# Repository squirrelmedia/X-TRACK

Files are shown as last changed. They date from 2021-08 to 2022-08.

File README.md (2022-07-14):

# X-TRACK
> 开源GPS自行车码表。
> 
> 拥有可显示实时位置的离线地图。
> 
> 支持记录和显示实时轨迹以及导出标准GPX格式的轨迹文件。
> 
> 全新设计的["页面生命周期管理"](https://github.com/FASTSHIFT/X-TRACK/tree/main/Software/X-Track/USER/App/Utils/PageManager)和["消息订阅发布框架"](https://github.com/FASTSHIFT/X-TRACK/tree/main/Software/X-Track/USER/App/Utils/DataCenter)。
>
> 演示视频：https://www.bilibili.com/video/BV1GB4y1K7VV



## GUI
> [LVGL V8](https://github.com/lvgl/lvgl)

## 硬件配置
* 1.主控: AT32F435CGU7 (主频:288MHz RAM:512KB ROM:1MB)
* 2.屏幕: ST7789 IPS 1.54inch SPI接口 240x240分辨率 60Hz刷新率
* 3.储存器: Micro SD CARD 32GB 
* 4.输入设备: 旋转编码器
* 5.RTC: MCU内置RTC时钟
* 6.加速度计: LSM6DSM (支持硬件计步输出)
* 7.地磁计: LIS3MDL
* 8.GPS: ATGM336H (BDS + GPS + GLONASS + GALILEO + QZSS + SBAS)
* 9.电池: Li-ion 3.7V 683030 700mAh
* 10.电源管理: LP5907-3.3 + MCP73831
* 11.外壳: 3D打印 光固化

## 功能
* 1.支持速度、距离、时间、卡路里、航向显示
* 2.拥有**离线地图**，支持显示实时位置，支持缩放
* 3.支持计步
* 4.支持经纬度、海拔显示
* 5.支持RTC自动根据GPS校准
* 6.支持记录轨迹，可导出[GPX格式](https://zh.wikipedia.org/wiki/GPX)的文件
* 7.支持掉电自动保存数据(JSON格式文件)
* 8.四小时续航 (持续工作，始终亮屏)
* 9.支持在[PC模拟器](https://github.com/FASTSHIFT/X-TRACK/tree/main/Software/X-Track/Simulator)模拟，脱离硬件调试(配置为**Release x86**)
* 10.支持显示实时轨迹
* 11.待续...

## 实物演示
### 测速
https://user-images.githubusercontent.com/26767803/120889722-1f8d8e80-c631-11eb-8294-df79f151dedb.mp4

### 历史轨迹显示([GPXSee](https://github.com/tumic0/GPXSee))


## 致谢
> 感谢[@davidce](https://www.geek-workshop.com/home.php?mod=space&uid=204)贡献的参考设计“[自制基于arduino的GPS地图导航系统3.0](https://www.geek-workshop.com/thread-8835-1-1.html)”。

> 感谢[@W-Mai](https://github.com/W-Mai)改进的[地图下载链接生成工具](https://github.com/W-Mai/XLocateDownloader/releases/download/1.0.0/MapDownloader.zip)、[地图下载器](https://github.com/W-Mai/XLocateDownloader)、[LVGL图片转换器(Python版)](https://github.com/W-Mai/lvgl_image_converter)、[批量文件重命名工具](https://github.com/W-Mai/filename_renamer)。

> 感谢[@Trigger-CN](https://github.com/Trigger-CN)的[UI设计](https://github.com/FASTSHIFT/X-TRACK/tree/main/ArtDesign)。

> 感谢[@MouriNaruto](https://github.com/MouriNaruto)的LVGL Visual Studio模拟器[lv_sim_visual_studio](https://github.com/lvgl/lv_sim_visual_studio)。

> 感谢[@dj140](https://github.com/dj140)编写[地图下载教程](https://github.com/FASTSHIFT/X-TRACK/blob/main/Tools/README.md)。

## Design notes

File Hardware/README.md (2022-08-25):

## 编译
* 参见: [编译说明](https://github.com/FASTSHIFT/X-TRACK/blob/main/Software/README.md)

## 硬件修改
* PCB打样的厚度选择**0.8mm**或**1mm**。
* 去除**D4**二极管，防止充电时自动开机，导致充电变慢和发热。
* 注意**D2**二极管方向，方向是和其他二极管相反的。否则会发生开机一段时间自动关机的情况。
* GPS模块需要由**HT1818Z3G5L**更换为**ATGM336H**(购买链接在下方)，否则外壳放不下。关于接线，GPS模块的**TX**脚接板子的**T焊盘**,**RX**脚接板子的**R焊盘**。注意GPS的天线**不要**碰到旁边的法拉电容，否则导致模块发热且收不到信号。
* 地磁计**LIS3MDL**和加速度计**LSM6DSM**在该系统中作用不大，又由于芯片涨价导致整机成本过高，可以不安装。
* MCU:**AT32F435CGU7**或**AT32F403ACGU7**
如果定不到货，可以尝试[@johnsbark](https://github.com/johnsbark)设计的[改进版硬件](https://github.com/FASTSHIFT/X-TRACK/tree/main/Hardware/X-TRACK%20%E6%94%B9%E8%BF%9B%E7%89%88)方案（红框内的MCU都可以进行尝试）。

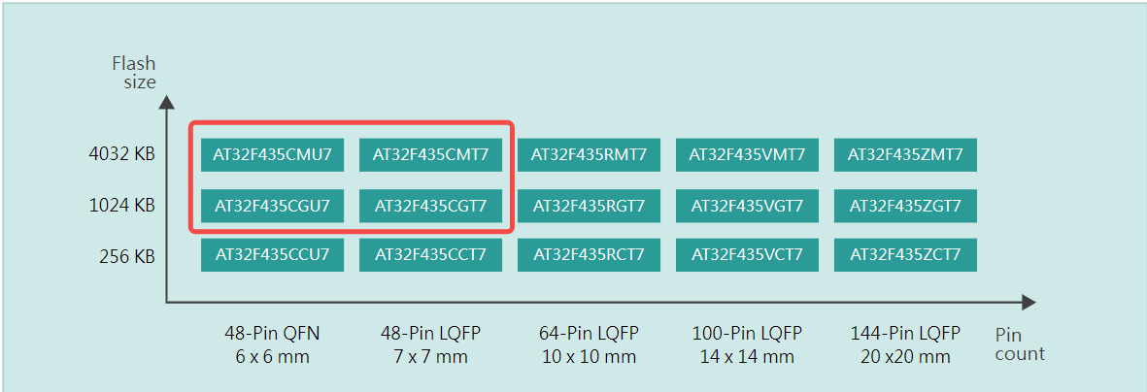
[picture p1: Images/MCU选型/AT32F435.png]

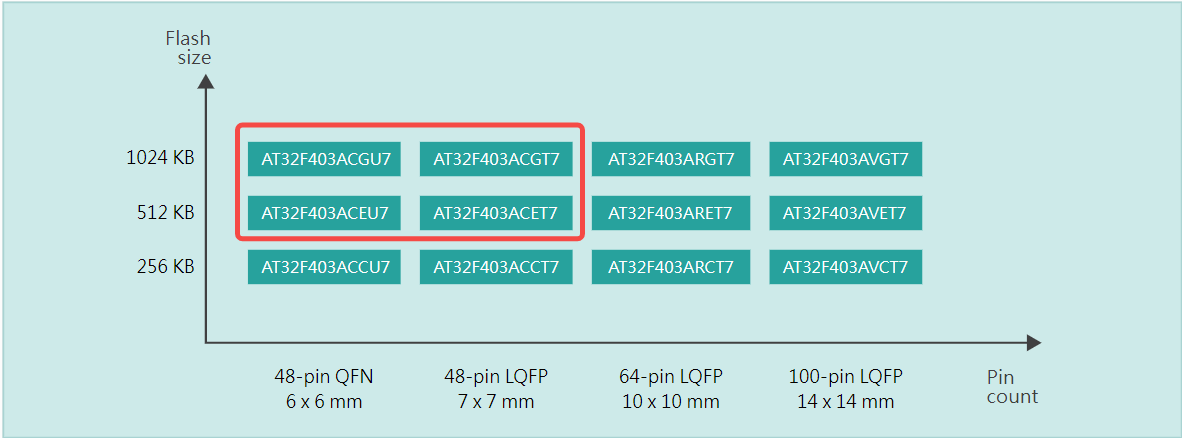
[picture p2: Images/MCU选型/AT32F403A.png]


* 关于其他品牌MCU替换的性能需求: 主频 >150M，RAM >=200K，FLASH >=512K，SPI速度 >=50Mbps。 

## 特殊器件购买链接
* 电池 (选择 683030) https://detail.tmall.com/item.htm?id=634173891714
* 旋转编码器 https://item.taobao.com/item.htm?id=598028191617
* 屏幕 (选择 裸屏) https://item.taobao.com/item.htm?id=600653923469
* 调试口 (选择 4P弯针) https://item.taobao.com/item.htm?id=522574977704
* 码表底座 (选择 竖向按装拓展片孔距M3*20~21mm[塑胶材料 3g]) https://item.taobao.com/item.htm?id=599529362799
* GPS模块 (ATGM336H) https://item.taobao.com/item.htm?id=603186739934
* AON3400 (AO3400 N沟道MOS管) https://item.taobao.com/item.htm?id=522574089119
* 侧盖螺丝 https://item.taobao.com/item.htm?id=522574685586
* Pad (焊接电池线的焊盘，非实体元件)

## 焊接
* [焊接教程](https://github.com/FASTSHIFT/X-TRACK/blob/main/Hardware/%E7%84%8A%E6%8E%A5%E8%B0%83%E8%AF%95%E6%8C%87%E5%8C%97.md)

## 常见故障排查
> GPS连不上
* 到开阔地带进行定位
* 进入系统信息页面查看GPS栏是否能获取到UTC时间
* 如果一直无法获取UTC时间，则检查GPS模块和MCU的硬件连接，确保通信波特率为9600
* 检查GPS天线朝向，参考下图

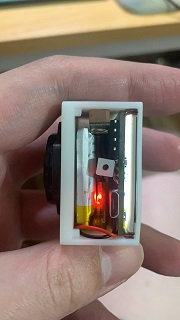
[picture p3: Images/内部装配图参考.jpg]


> 地图不显示
* 在首次定位成功前，默认加载的地图区域是北京，等待定位成功或者修改**SystemSave.json**里的经纬度配置
* 检查状态栏是否有SD卡图标
* 检查地图文件路径是否为`/MAP/z/x/y.bin`
* **不要使用旧版地图工具**

> 不开机 & 关不了机
* 长按编码器开关机
* 检查供电是否正常，MCU和其他器件上的电压是否是3.3V

> 开机了但黑屏
* 检查屏幕排线和MCU间是否短路或虚焊
* 检查背光是否有电压

> SD卡无法读取
* 在系统信息页面查看"Storage"项，是否能正常读取到SD卡容量和类型
* 检查SD卡座和MCU间是否有短路或虚焊
* 检查SD卡格式是否为FAT32

> SD卡内没有生成**SystemSave.json**配置文件
* **SystemSave.json**在第一次关机后自动生成

> 地图坐标有恒定偏移
* 尝试修改SD卡根目录下的**SystemSave.json**里的**useWGS84**选项[配置地图坐标系统](https://github.com/FASTSHIFT/X-TRACK/tree/main/Software#%E7%B3%BB%E7%BB%9F%E9%85%8D%E7%BD%AE%E6%96%87%E4%BB%B6)

> 速度不准
* 不同厂家的GPS模块性能不一，测得的速度可能会有小幅度跳动(<±2KM/h)
* 检查GPS天线朝向，参考第一点
* 更换GPS模块

> PC模拟器上无法显示地图/显示颜色异常
* MAP地图文件夹放在X-TRACK工程的根目录`~/X-TRACK/MAP/`
* 修改**SystemSave.json**里的经纬度配置到希望显示地图的地方
* 确认生成的地图文件命名格式为`/z/x/y.png`
* 修改**SystemSave.json**的`"sysConfig.mapExtName"`项目，将`"bin"`改为`"png"`

## 2.0寸屏版本
https://github.com/FASTSHIFT/X-TRACK/tree/2.0-inch by[@HanfG](https://github.com/HanfG)

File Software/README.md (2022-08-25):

## 编译说明
* MCU固件: 务必使用**Keil v5.25**或以上的版本进行编译（旧版本编译器不能完全支持**C++ 11**的语法），在Keil中编译器版本设置为ARM Compiler 5。
* 编译前需要安装[Artery](https://www.arterytek.com/cn/index.jsp)官方Pack，**为了确保顺利编译请安装[Software/Pack](https://github.com/FASTSHIFT/X-TRACK/tree/main/Software/Pack)目录下的指定版本**。

* 如果安装Pack后，Keil依然报以下这类错误，可能是之前安装了 Keil v4 兼容包 (MDK v4 Legacy Support) 导致的，请尝试**卸载此包或重新安装 Keil v5**。

`Error #540: 'Keil::Device:StdPeriph Drivers:ADC:1.0.1' component is not available for target 'X-Track'`
 
  ### 注意
  **不要修改芯片选型**，因为修改芯片选型后启动文件会重新生成，堆栈大小会恢复默认值，而使用默认的栈大小会导致**栈溢出**。现象是启动后立即蓝屏，提示发生**HardFault**(如下图所示)，串口会输出详细的错误信息。如果确实需要修改芯片选型，请参考工程原始的启动文件进行修改。



## VS模拟器配置
* 编译：使用`Visual Studio 2019`编译，配置为`Release` `x86`模式，`Debug`模式需要额外安装[ASAN](https://docs.microsoft.com/en-us/cpp/sanitizers/asan?view=msvc-170)插件。
* 文件配置：

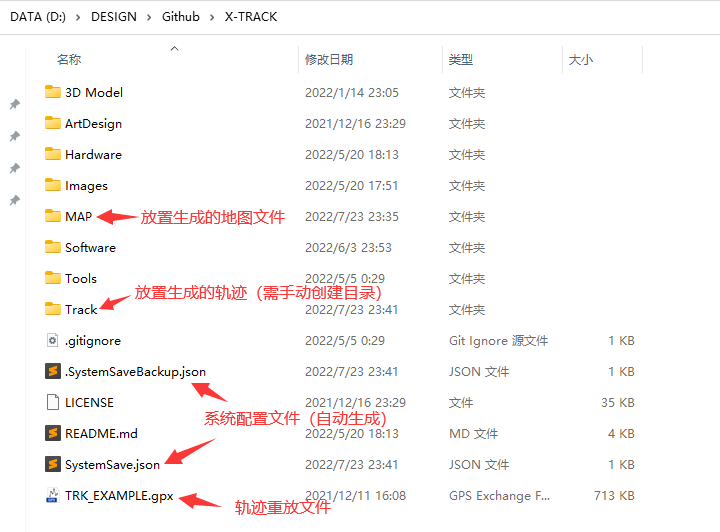
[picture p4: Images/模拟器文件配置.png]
images


## 系统配置文件
系统会在根目录下自动生成`SystemSave.json`的文件，用于储存和配置系统参数:
```javascript
{
  "sportStatus.totalDistance": 0,              // 总里程(m)
  "sportStatus.totalTimeUINT32[0]": 0,         // 总行驶时间(ms)，低32位
  "sportStatus.totalTimeUINT32[1]": 0,         // 总行驶时间(ms)，高32位
  "sportStatus.speedMaxKph": 0,                // 最高时速(km/h)
  "sportStatus.weight": 65,                    // 体重(kg)
  "sysConfig.longitude": 116.3913345,          // 上次开机记录的位置(经度)
  "sysConfig.latitude": 39.90741348,           // 上次开机记录的位置(纬度)
  "sysConfig.soundEnable": 1,                  // 系统提示音使能(1:开启，0:关闭)
  "sysConfig.timeZone": 8,                     // 时区(GMT+)
  "sysConfig.language": "en-GB",               // 语言(尚不支持多语言切换)
  "sysConfig.arrowTheme": "default",           // 导航箭头主题(default:全黑，dark:橙底黑边，light:橙底白边)
  "sysConfig.mapDirPath": "/MAP",              // 存放地图的文件夹路径
  "sysConfig.mapExtName": "bin",               // 地图文件扩展名
  "sysConfig.mapWGS84": 0                      // 坐标系统配置(0:GCJ02, 1:WGS84)
}
```

## 目录结构
```
 X-Track
    ├─ArduinoAPI                -- 通用 Arduino API 抽象层
    ├─Doc                       -- 芯片相关文档
    ├─Libraries                 -- 硬件驱动程序
    │  ├─Adafruit_GFX_Library   -- Adafruit_GFX轻量级图形库
    │  ├─Adafruit_ST7789        -- ST7789屏幕驱动
    │  ├─ButtonEvent            -- 按键事件库
    │  ├─cm_backtrace           -- ARM Cortex-M 系列 MCU 错误追踪库
    │  ├─LIS3MDL                -- LIS3MDL地磁计驱动
    │  ├─LSM6DSM                -- LSM6DSM陀螺仪加速度计驱动
    │  ├─MillisTaskManager      -- 合作式任务调度器
    │  ├─SdFat                  -- 文件系统
    │  ├─StackInfo              -- 栈空间使用统计库
    │  └─TinyGPSPlus            -- NMEA协议解析器
    ├─MDK-ARM_F403A             -- AT32F403A Keil工程
    ├─MDK-ARM_F435              -- AT32F435  Keil工程
    ├─Simulator                 -- Visual Studio LVGL PC模拟器
    ├─Tools                     -- 实用工具
    └─USER                      -- 用户程序
        ├─App                   -- 应用层
        │  ├─Common             -- 通用程序
        │  │  ├─DataProc        -- 应用后台数据处理
        │  │  ├─HAL             -- 硬件抽象层定义/Mock实现
        │  │  └─Music           -- 操作音管理
        │  ├─Config             -- 应用配置文件
        │  ├─Pages              -- 页面
        │  │  ├─Dialplate       -- 表盘页面
        │  │  ├─LiveMap         -- 地图页面
        │  │  ├─Startup         -- 开机页面
        │  │  ├─StatusBar       -- 状态栏
        │  │  ├─SystemInfos     -- 系统信息页面
        │  │  └─_Template       -- 页面模板
        │  ├─Resource           -- 资源池
        │  │  ├─Font            -- 字体
        │  │  └─Image           -- 图片
        │  └─Utils              -- 通用应用层组件
        │      ├─ArduinoJson    -- JSON库
        │      ├─DataCenter     -- 消息发布订阅框架
        │      ├─Filters        -- 常用滤波算法库
        │      ├─GPX            -- GPX生成器
        │      ├─GPX_Parser     -- GPX解析器
        │      ├─lv_allocator   -- 自定义allocator
        │      ├─lv_anim_label  -- 文本动画组件
        │      ├─lv_ext         -- lvgl功能扩展
        │      ├─lv_img_png     -- PNG显示组件
        │      ├─lv_poly_line   -- 多段线控件
        │      ├─MapConv        -- WGS84/GCJ02 地图坐标转换器
        │      ├─new            -- new/delete 重载
        │      ├─PageManager    -- 页面调度器
        │      ├─PointContainer -- 坐标压缩容器
        │      ├─ResourceManager-- 资源管理器
        │      ├─StorageService -- KV储存服务
        │      ├─Stream         -- Arduino Stream 流式库
        │      ├─TileConv       -- 瓦片坐标转换器
        │      ├─Time           -- 时间转换算法库
        │      ├─TonePlayer     -- 异步方波音乐播放器
        │      ├─TrackFilter    -- 流式轨迹坐标拐点/线段提取器
        │      └─WString        -- Arduino WString 字符串库
        ├─HAL                   -- 硬件抽象层
        └─lv_port               -- lvgl与硬件的接口
```

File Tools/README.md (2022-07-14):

# 地图下载说明

## 1.下载安装[Crimson/地图下载器](https://gitee.com/CrimsonHu/java_map_download/)

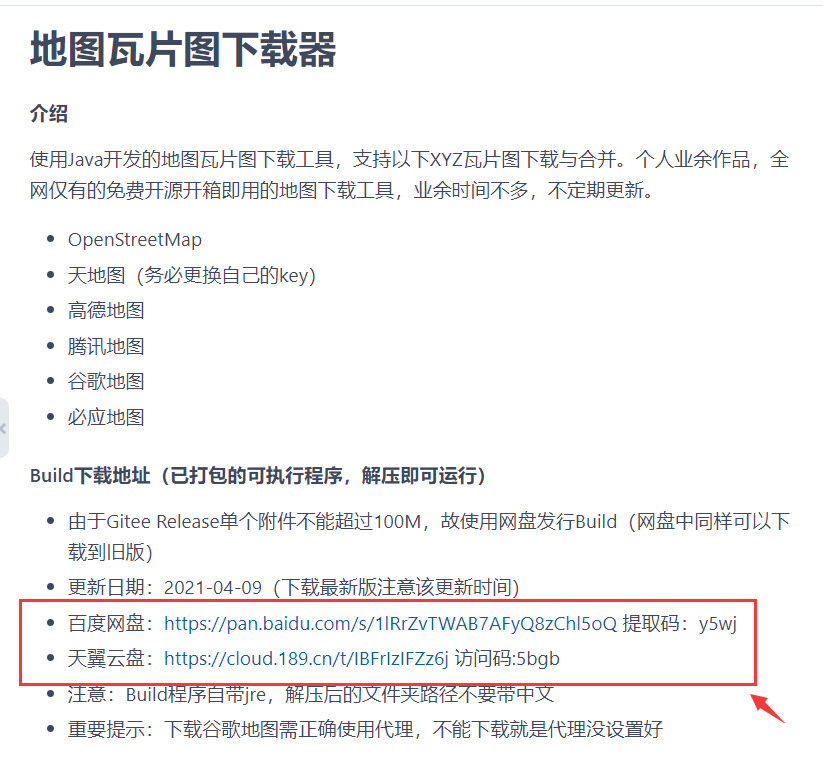
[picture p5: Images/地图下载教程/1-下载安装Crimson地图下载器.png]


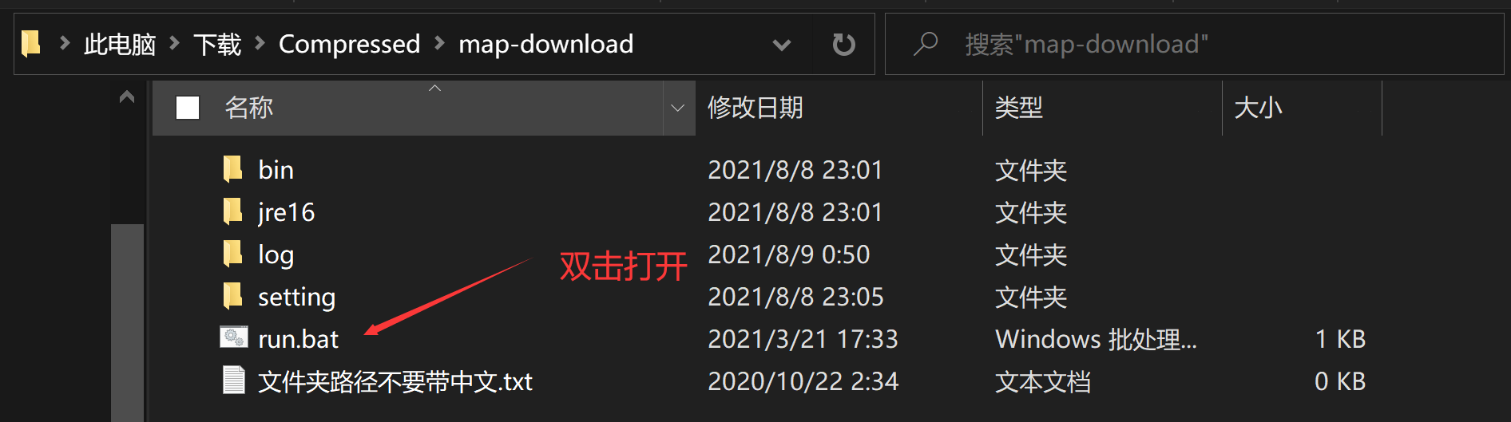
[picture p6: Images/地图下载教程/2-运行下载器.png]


## 2.选择要下载的地图区域
 * 选择自己所在区域下载即可，**切勿选择过大范围**，下载区域设置小一些后续下载会快很多。
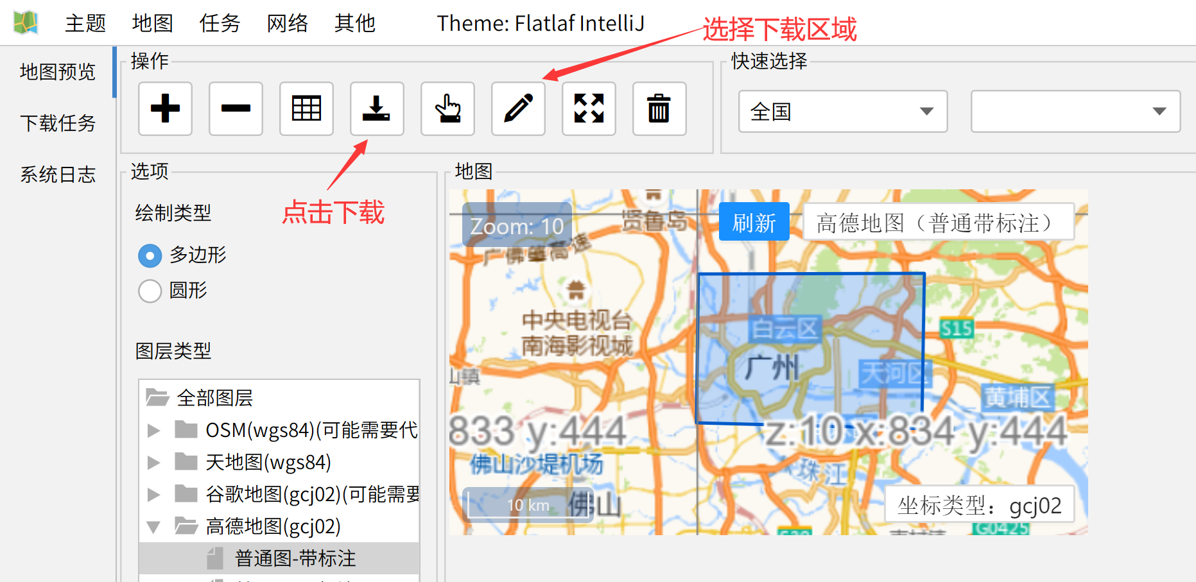
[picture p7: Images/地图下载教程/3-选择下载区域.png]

## 3.下载地图
 * 下载地图等级根据自己喜好选择，等级越高地图越详细，但是文件也越大（建议只勾选**0~16级**，如果出现0~2级下载失败的情况，可以不勾选）。命名格式为`/z/x/y.png`格式，保存路径新建一个`MAP`文件夹
 
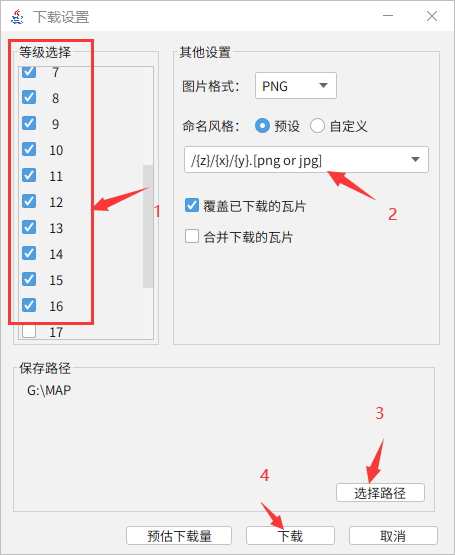
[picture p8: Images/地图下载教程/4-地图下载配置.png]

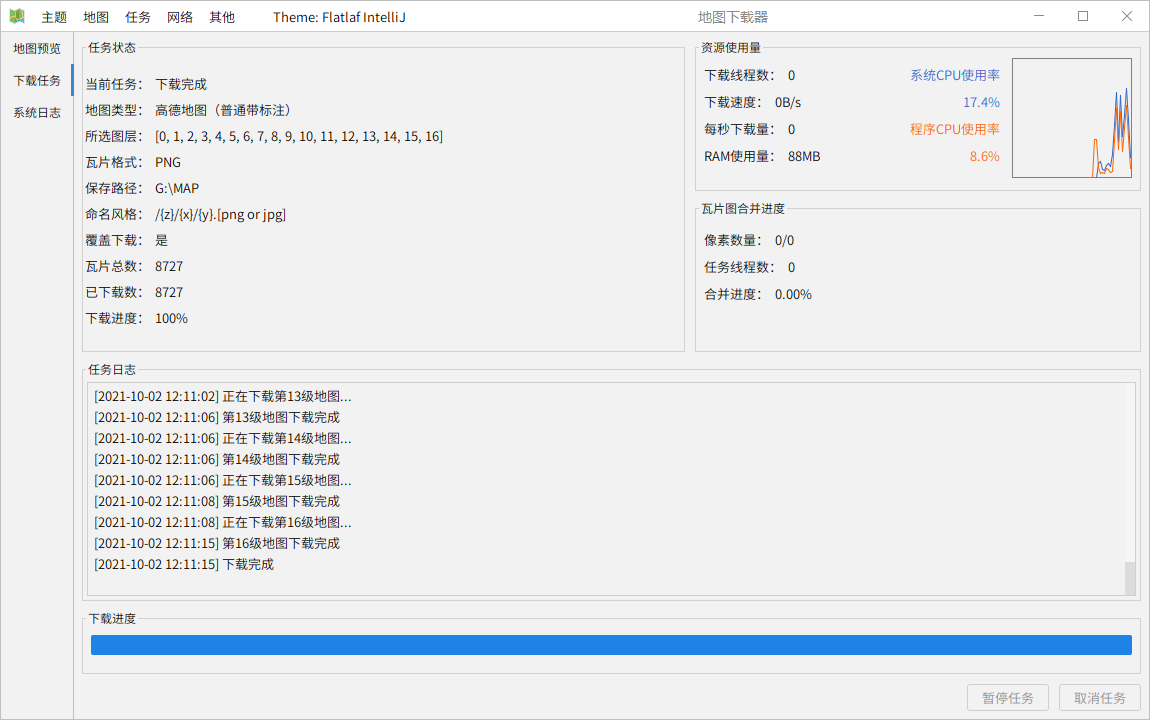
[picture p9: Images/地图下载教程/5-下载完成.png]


## 4.转换地图文件
* 下载完成后，使用`Tools`文件夹下的`TilesConverterForLVGL.exe`进行转换（[使用教程](https://github.com/FASTSHIFT/X-TRACK/tree/main/Images/MapConverter%E4%BD%BF%E7%94%A8%E6%95%99%E7%A8%8B)）




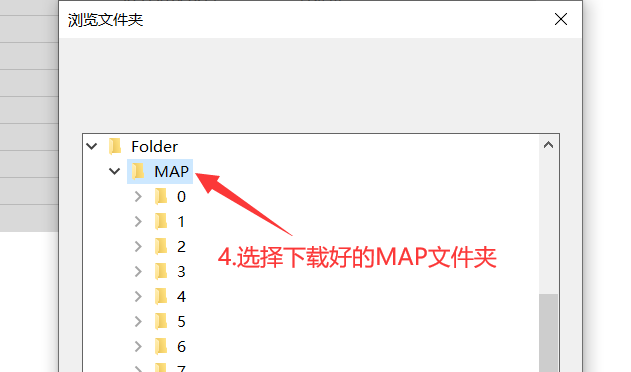
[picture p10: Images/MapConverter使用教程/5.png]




## 5.拷贝"MAP"文件夹至SD卡根目录
### 注意：
 * SD卡需要格式化为**FAT32格式**。
 * SD卡插入开机以后，会在第一次关机时自动创建`SystemSave.json`文件，其中：
 > 通过`"mapDirPath"`设置地图源文件夹，默认路径为`"/MAP"`（SD卡可以储存多个地图源，通过此选项切换）
 > 
 > 通过`"mapWGS84"`设置坐标系统，如果发现地图偏移请尝试修改。
 * `SystemSave.json`文件详细说明见[编译说明](https://github.com/FASTSHIFT/X-TRACK/blob/main/Software/README.md)。

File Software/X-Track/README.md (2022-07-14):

# X-TRACK 更新日志
> https://github.com/FASTSHIFT/X-TRACK

## [v0.1] - 2021-3-21
* 1.框架搭建完成，全新MVP(Model-View-Presenter)架构
* 2.更新3D Model，门板完美安装
* 3.修复串口缓冲队列过载导致GPS解析连续失败的BUG
* 4.添加长按开机功能
* 5.添加计步显示
* 6.速度显示使用kph为单位
* 7.添加新的ButtonEvent库
* 8.添加Filters数字滤波器库 
* 9.添加新的TonePlayer库
* 10.格式化LIS3DMDL库的代码
* 11.格式化LISM6DSM库的代码
* 12.添加新的简易表盘页面
* 13.为LiveMap页面添加group，优化Encoder交互
* 14.LiveMap已可以正常显示航向，使用GPS的航向信息
* 15.重新校准MapConv地图坐标
* 16.添加HAL_AHRS姿态解算
* 17.添加HAL_Encoder接口
* 18.添加HAL_GPS串口透传，可使用上位机对GPS模块进行配置
* 19.添加GNSSToolKit_Lite配置工程
* 20.添加lv_get_indev()
* 21.添加__wfi()，可能省点电

## [v0.2] - 2021-4-19
* 1.添加ArtDesign工程，使用Adobe Illustrator
* 2.添加异步无锁Buffer库：PingPongBuffer
* 3.删除离线图片和字体转换工具
* 4.修改页面ID格式：DialplatePage->Pages/Dialplate
* 5.添加消息发布订阅框架：DataCenter
* 6.将HAL.h转移至应用层
* 7.HAL: Clock_GetValue->Clock_GetInfo
* 8.在PC模拟器上使用PC的电量显示
* 9.更新PageManager
* 10.降低SD热插拔监控扫描速度
* 11.删除Music_Astronomia
* 12.在编码器按下时忽略滚动，减少误触
* 13.更新Dialplate页面
* 14.更新LiveMap页面

## [v0.3] - 2021-5-12
* 1.lvgl迁移至v8.0.0
* 2.PingPongBuffer转移至App/Utils/DataCenter，以提供无锁的线程安全的数据块访问，添加volatile关键字
* 3.VS工程在Debug下启用AddressSanitizer，捕获异常的内存操作
* 4.Heap和Stack调整
* 5.更新ButtonEvent库
* 6.更换新的文件系统接口lv_fs_if
* 7.系统配置文件SysConfig.h -> Config.h
* 8.Utils添加WString for PC
* 9.ResourceManager更新，使用std::vector作为资源池
* 10.PageManager更新，lvgl-v8适配，简化子模块命名，使用std::vector作为页面池，使用std::stack作为页面栈
* 11.地图坐标转换器MapConv更新，但未找到更精确的地图坐标换算算法
* 12.去除lv_theme_custom
* 13.添加GPX库，将来用于生成GPX格式的标准轨迹记录文件
* 14.使用C++ template重写Filters滤波器合集库
* 15.数据发布订阅处理中心DataCenter更新，添加错误码、通知、数据提交等功能
* 16.StatusBar更新，添加背景色柔和渐变、电池充电等特效
* 17.LiveMap页面更新，新的滚动条和info按钮
* 18.Dialplate页面更新，操作按钮已可以使用
* 19.数据处理节点DP_SportStatus更新，更新卡路里换算算法、距离、速度滤波等处理方法
* 20.添加新的数据处理节点DP_Recorder，用于记录轨迹于SD卡中
* 21.电池AD采样使用中断模式，而不使用DMA
* 22.文件系统SD对象不再全局共享
* 23.屏蔽开机启动时Encoder按键事件

## [v0.4] - 2021-5-16
* 1.lvgl更新
* 2.支持导出GPX格式的轨迹记录文件，推荐使用[GPXSee](https://github.com/tumic0/GPXSee)查看轨迹
* 3.Clock_info_t结构体成员单词全拼
* 4.LiveMap页面更新，改进的操作方式与显示特效
* 5.去除MAP数据映射宏，使用lv_map替代
* 6.SD支持时间戳记录，支持自动检测和创建缺失的文件夹

## [v0.5] - 2021-5-23
* 1.添加SystemInfos页面
* 2.添加IMU和地磁MAG数据处理节点
* 3.修改轨迹记录默认文件名
* 4.规范lv_event成员参数获取方式
* 5.修复DataCenter缓冲区读取释放BUG
* 6.添加Version.h存放版本信息
* 7.HAL::GPS_Info_t添加hour_utc成员

## [v0.6] - 2021-5-31
* 1.更新lvgl
* 2.添加App_Uninit()，绑定关机事件
* 3.添加DP_LIST.inc，更优雅的数据处理节点注册方式
* 4.添加IMU/MAG_Commit，向数据中心提交数据
* 5.添加StorageService数据储存服务，使用JSON格式储存数据
* 6.添加ArduinoJson解析库
* 7.运动数据处理节点 sportStatusInfo -> sportStatus，添加储存绑定
* 8.去除HAL::AHRS
* 9.GPS在未定位成功时，经纬度海拔统一置零
* 10.HAL::Power添加关机事件回调
* 11.CONTROLLER -> PRESENTER
* 12.添加Startup页面，展示开机动画
* 13.LiveMap地图页面，在未定位成功时的默认位置为天安门
* 14.StatusBar状态栏，函数AppearAnimStart -> Appear 
* 15.解决SystemInfos页面在自动管理Cache时退出页面造成的Crash
* 16.修复MAG数据显示的bug
* 17.DataCenter添加主账户AccountMain，自动订阅所有的子节点，用于发送通知
* 18.PageManager在删除root时需要使用异步删除lv_obj_del_async()，在root动画生命周期结束后删除
* 19.降低GPS和Sensor的数据更新频率，分别为5Hz和1Hz

## [v0.7] - 2021-6-5
* 1.更新拆分STL模型文件
* 2.TonePlayer转移至App/Utils
* 3.在关机时自动保存正在记录的轨迹文件
* 4.优化轨迹记录操作体验
* 5.DataCenter合并定时器回调到AccountEvent
* 6.AccountEvent添加Account* 参数
* 7.添加DATA_PROC_INIT_DEF节点定义
* 8.添加StatusBar状态栏、MusicPlayer播放器、TzConv时区转换器数据节点
* 9.优化电池电量滤波算法 Hysteresis + MedianQueue
* 10.转移STORAGE_VALUE_REG宏定义至DataProc_Def.h
* 11.在SD插入时自动加载JSON系统配置文件
* 12.添加Common/Music
* 13.优化DataCenter和PageManager日志输出等级
* 14.优化GPX库
* 15.优化PAGE_STASH_POP
* 16.去除PageManager::Pop函数的stash参数
* 17.添加Arduino Time时间转换库
* 18.去除GPS_Info_t的hour_utc成员，使用TzConv进行时区转换

## [v0.8] - 2021-6-15
* 1.格式化所有代码
* 2.APP_Init添加ACCOUNT_SEND_CMD，简化Account通知调用
* 3.dataCenter("Bilibili") -> dataCenter("CENTER")
* 4.添加SysConfig节点，用于保存系统设置
* 5.Power节点使用Account通知方式调用MusicPlayer，而不使用HAL::Audio_PlayMusic
* 6.去除HAL::Backlight_UpdateBKP()和Backlight_GetBKP()
* 7.DialplateModel添加节点名称验证
* 8.LiveMapModel添加节点名称验证
* 9.DataCenter添加Account双buffer动态内存申请检查
* 10.Account::GetPublisherLen() -> GetPublisherSize(), GetSubscribeLen() -> GetSubscribeSize()
* 11.更新lv_anim_timeline，支持设置progress，已提交至lvgl主线
* 12.去除lv_obj_ext_func不常用的函数
* 13.StorageService扩大JSON_BUFFER_SIZE 256 -> 512, 添加字符串类型参数读取返回值检查
* 14.添加硬件定时器配置到Config.h
* 15.修改版权声明遗留拼写错误

## [v0.9] - 2021-6-24
* 1.更新ButtonEvent，支持EVENT_LONG_PRESSED_RELEASED
* 2.调整lvgl内存池，32KB -> 64KB
* 3.HAL_GPS支持读取csv格式的文件，在PC上模拟位置变化
* 4.更新LiveMap页面，支持实时绘制运动轨迹，支持自适应分辨率动态加载地图
* 5.更新Startup页面，移除默认样式，并在开机动画过程中屏蔽Encoder事件
* 6.修复SystemInfos页面因为忘记释放style.focus导致的内存泄漏
* 7.优化DataCenter的Account的cache申请失败判断逻辑
* 8.添加lv_allocator，使用lvgl接管std::vector内存管理实现
* 9.更新MapConv，MapKeyRootName -> MapFilePath，ConvertMapTile() -> ConvertPosToTile()
* 10.添加TileConv，通用的瓦片动态加载算法实现
* 11.添加TrackFilter轨迹过滤器，包含TrackPointFilter曲线关键点提取算法和TrackLineFilter曲线区域裁剪算法
* 12.HAL::Encoder添加Encoder_SetEnable()方法

## [v1.0] - 2021-7-1
* 1.更新lvgl v8.1.0 dev
* 2.添加TrackFilter数据处理节点，储存过滤后的拐点坐标
* 3.优化DP_Clock RTC自动校准
* 4.优化DP_GPS提示音播放，添加cache，使用Publish向订阅者推送数据，减少定时轮询拉取
* 5.添加GPX_Parser，支持直接解析GPX数据还原轨迹
* 6.Config.h转移到App
* 7.页面添加namespace Page命名空间
* 8.优化LiveMap轨迹显示，在轨迹记录时显示轨迹，使用lambda表达式替换部分回调函数
* 9.优化StatusBar充电动画
* 10.DataCenter添加注释
* 11.PageManager添加注释
* 12.lv_allocater添加遗漏的运算符重载
* 13.添加Utils/Stream，来自Arduino
* 14.转移CommmonMacro.h到HAL，去除Basic文件夹

## [v1.1] - 2021-7-7
* 1.支持在GPX中记录海拔和时间，可在GPXSee查看爬升和速度统计
* 2.更新Startup页面，使用匿名函数回调
* 3.更新SystemInfos页面，添加Author署名和Build时间，电池状态 State -> Status
* 4.更新lvgl
* 5.更新GPX生成库，添加遗漏的time_成员
* 6.尝试将lvgl部分函数放在RAM中执行，但是执行速度提升不明显

## [v1.2] - 2021-7-11
* 1.添加StackInfo库，支持在裸机环境下测量栈使用情况
* 2.Stack_Size 0x2500 -> 0x1000
* 3.更新DP_Storage数据储存节点，支持拉取储存器使用情况
* 4.更新Config.h，添加显示器分辨率和缓冲区配置
* 5.添加触控逻辑
* 6.修复StatusBar充电动画闪烁的BUG，添加SD卡图标
* 7.SystemInfos页面添加SD卡状态监测显示

## [v1.3] - 2021-7-18
* 1.Config.h添加传感器使能配置选项
* 2.DataCenter添加cache自动初始化置0
* 3.添加Microsoft官方TileSystem解析库，供mapConv调用

## [v1.4] - 2021-7-24
* 1.更新lvgl
* 2.更新MapConv，统一使用GPS_Transform校准坐标
* 3.更新HAL::GPS模拟，支持航向和速度模拟
* 4.修改HAL::GPS_Info_t的 compass -> course
* 5.使用合入lvgl主线的lv_anim_timeline，使用lv_anim_timeline_wrapper封装动画组
* 6.更新Startup页面，新的开机动画
* 7.LV_IMG_CACHE_DEF_SIZE设置为0

## [v1.5] - 2021-8-1
* 1.lvgl更新
* 2.调整Stack size: 0x1500 -> 0x2000，处理更大的JSON文件
* 3.更新Storage节点，支持获取SD卡容量，支持自动获取地图缩放等级(OSM)
* 4.优化GPS节点，减少在GPS信号不稳定时频繁的提示音
* 5.优化SportStatus节点，支持在JSON文件中配置体重
* 6.优化SysConfig节点，支持在JSON配置默认经纬度，地图源(Bing/OSM)，soundDisable -> soundEnable
* 7.重构MapConv地图坐标转换器，支持动态配置地图源，地图坐标数据类型uint32_t -> int32_t，合并TileSystem和GPS_Transform
* 8.HAL添加SD_GetCardSizeMB()
* 9.更新Config.h，转移部分配置选项到JSON
* 10.更新Dialplate页面，卡路里单位cal -> k，优化编码器交互wrap = false
* 11.更新LiveMap页面，优化level自适应显示，使用SysConfig配置的默认位置
* 12.更新SystemInfos页面，支持显示SD卡容量
* 13.修复lv_fs_sdfat错误的指针类型转换，优化目录读取接口
* 14.lvgl内存池 64K -> 72K
* 15.WString使用lvgl的内存池
* 16.修复GPX轨迹文件<\ele>丢失问题(可能是内存碎片和heap过小导致WString realloc失败)

## [v1.6] - 2021-8-7
* 1.更新ArtDesign，新的导航箭头设计
* 2.更新lv_drivers，去除坐标超界警告
* 3.去除lv_examples，减少工程体积
* 4.调整模拟器的LV_FS_PC_PATH定义，指定到Software所在目录，方便读取地图
* 5.开机页面重命名: StartUp -> Startup
* 6.更新DP_SysConfig，mapSource -> mapDirPath指定地图目录，添加 WGS84/GCJ02 坐标系统切换，添加arrowTheme导航箭头主题切换
* 7.更新DP_Storage，适配新的MapConv，支持所有地图源缩放level范围自适应
* 8.更新DP_TrackFilter，适配新的MapConv
* 9.HAL添加Backlight_ForceLit()，支持强制点亮屏幕背光
* 10.更新模拟器的HAL_GPS，支持获取GPX点之间的时间差
* 11.更新Config.h，去除旧的Bing地图配置
* 12.更新LiveMap页面，支持修改导航箭头主题
* 13.更新GPX_Parser，添加海拔和时间解析
* 14.重构MapConv，废弃旧的Bing地图存放格式和地图下载器。使用[Crimson/地图下载器](https://gitee.com/CrimsonHu/java_map_download/)下载地图，文件存放格式为`/z/x/y.bin`
* 15.更新DisplayFault，在进入HardFault状态时强制点亮背光
* 16.更新HAL_Power，优化电压显示

## [v1.7] - 2021-9-3
* 1.调整Heap_Size 0x00002000 -> 0x00000200
* 2.调整lvgl内存池大小，LV_MEM_SIZE 72K -> 80K
* 3.更新lv_drivers
* 4.更新lvgl
* 5.DataCenter使用lvgl内存池
* 6.使用std::abs()替代宏实现的ABS()
* 7.更新DP_Storage
* 8.更新DP_SysConfig，调整结构体成员，添加timeZone和mapExtName，在关机时保存位置
* 9.更新DP_TrackFilter，使用地图上的Point格式替代旧的经纬度
* 10.更新DP_TzConv，GMT_OffsetHours -> sysCfg.timeZone
* 11.更新HAL.h，添加Memory_DumpInfo()堆栈使用统计
* 12.更新HAL_GPS模拟，修复diffTime = 0导致的gpsInfo.speed = inf
* 13.更新Config.h，添加LiveMap的Debug模式配置，PNG解码库使能配置等。转移Hardware Configuration至HAL_Config.h
* 14.更新Dialplate页面，使用lv_group_get_default()获取统一的group
* 15.重构LiveMap页面，添加LiveMap的Debug模式，使用lv_group_get_default()获取统一的group，适配新的轨迹过滤算法
* 16.更新StartUp页面，关闭LOGO滚动
* 17.更新SystemInfos，使用lv_group_get_default()获取统一的group
* 18.更新DataCenter，统一使用lv_allocator分配内存
* 19.添加lv_lib_png，限于内存大小暂不使用
* 20.添加lv_monkey，实现简单压力测试
* 21.添加lv_multi_line，实现轨迹的多段线绘制，提升lv_line复用率，极大节省内存
* 22.更新MapConv，支持自定义文件扩展名，添加ConvertMapPos实现不同level间的坐标换算
* 23.更新TileSystem，使用namespace替换class，免去无意义的实例化
* 24.添加new、delete重载，统一使用lvgl内存池
* 25.扩展StorageService的内存，JSON_BUFFER_SIZE 1024->2048
* 26.更新TrackFilter，修复二级滤波拐点丢失问题。使用TrackLineFilter实现可视区轨迹裁剪，节省内存，提升绘制效率。
* 27.更新lv_fs_sdfat接口，使用new和delete替换lv_mem_alloc和lv_mem_free
* 28.更新lv_port_indev，去除lv_port_indev_get()，创建全局默认group
* 29.添加HAL::Memory_DumpInfo()，由于要使用__heapstats()读取heap信息，关闭microlib
* 30.添加rt_sys.cpp，实现一些C底层接口
* 31.读取StackInfo从main.cpp转移至HAL::Memory_DumpInfo()

## [v1.8] - 2021-9-14
* 1.StackInfo库 StackInfo_GetSize -> StackInfo_GetTotalSize
* 2.移除多余的RTE/Device
* 3.Common/HAL模拟器实现转移到Simulator\LVGL.Simulator\HAL
* 4.VS模拟器HAL_GPS适配新的GPX_Parser
* 5.更新lv_conf.h LV_CIRCLE_CACHE_SIZE 8 -> 32
* 6.更新lv_fs_pc，去除无用代码
* 7.更新LVGL.Simulator，lv_png_init和lv_monkey_create转移至App_Init初始化
* 8.更新lvgl主程序
* 9.更新App初始化，调整Storage和SysConfig的初始化顺序，修复错误的全屏滑动
* 10.更新DataProc初始化，center实例化转移到函数外部，DP_DEF宏全大写
* 11.更新DataProc声明，ConvTime -> MakeTimeString，去除IMU_Commit和MAG_Commit
* 12.更新Storage_Basic_Info_t，添加type成员，支持获取SD卡类型
* 13.更新DP_Clock，ConvTime -> MakeTimeString
* 14.更新DP_IMU，去除IMU_Commit机制，使用回调进行数据提交
* 15.更新DP_MAG，同上
* 16.更新DP_Recorder，合并变量至Recorder_t结构体，添加RECORDER_GPX宏配置
* 17.更新DP_Storage，适配新的StorageService，添加SD卡类型获取
* 18.更新DP_TrackFilter，PointVector_t不再使用lv_allocator
* 19.更新HAL，添加Display和FaultHandle抽象层，以及IMU和MAG的CommitCallback，获取SD卡类型的函数
* 20.去除lv_allocator依赖，统一使用重载的new和delete进行分配
* 21.更新SystemInfos页面，SD卡状态指示 "Detect" -> "Status"，支持显示SD卡类型，在Sensor Config未开启时数据全部置0
* 22.调整ResourcePool的Font Default设置
* 23.ArduinoJson库的DynamicJsonDocument使用lvgl内存池分配内存
* 24.更新DataCenter/Account，"Push" -> "Publish"
* 25.更新DataCenter和PageManager的LOG写法
* 26.更新GPX_Parser，添加错误码
* 27.lv_lib_png使用lvgl内存池分配内存
* 28.更新lv_monkey，添加新的配置选项
* 29.更新MapConv，ConvertMapPos -> ConvertMapLevelPos
* 30.在VS模拟器上对new/delete进行重载，但是由于ASAN导致重定义冲突，只在Release下重载
* 31.更新PageManager，解决lv_anim_exec_xcb_t回调的lv_coord_t和int32_t混用问题，修复LOAD_ANIM_NONE页面切换的BUG
* 32.更新StorageService，支持静态和动态内存分配切换
* 33.去除USER/Display，转移至HAL层
* 34.优化lv_port，使用统一的初始化函数，与硬件驱动解耦，lv_fs_sdfat -> lv_port_fs_sdfat
* 35.修复HAL_Buzz静音模式下的错误开机音
* 36.更新HAL_Config，支持GPS缓冲区过载检测，支持配置Power的开关机延时时间
* 37.更新HAL_Power，合并变量到Power_t
* 38.更新HAL_SD_CARD，支持获取SD卡类型，SD_CardSizeMB -> SD_CardSize

## [v1.9] - 2021-10-1
* 1.修复ArduinoAPI中未初始化变量
* 2.去除lv_fs_pc中未使用的函数
* 3.去除unistd.h
* 4.更新lvgl主程序
* 5.Resource管理器，Resource. -> ResourcePool::
* 6.添加Utils/PointContainer组件
* 7.DP_Storage添加地图缩放级别错误检查
* 8.DP_TackFilter添加PointContainer组件适配，减少75%内存占用，极大提升轨迹录制容量
* 9.多段线组件lv_multi_line -> lv_poly_line
* 10.更新ArduinoJson
* 11.Display_DumpCrashInfo report -> info
* 12.更新HAL_Power，不使用ADC中断模式

## [v2.0] - 2021-11-14
* 1.Arduino API底层重构
* 2.添加MillisTaskManager任务调度器
* 3.lvgl使用标准memset和memcpy
* 4.更新lvgl v8.1.0
* 5.DataCenter错误码枚举 ERROR_XXX -> RES_XXX
* 6.修改DP节点的结构体初始化方式，不使用默认初始化
* 7.优化DP_SportStatus在临时信号丢时的数据统计处理
* 8.修复StorageService文件结尾读取错误导致的crash
* 9.添加lv_settings，暂未移植
* 10.添加传感器自动扫描，防止未安装传感器导致的开机卡死
* 11.使用event携带user_data
* 12.优化new重载
* 13.修复HAL_Power错误的关机处理
* 14.添加SystemSave.json自动备份功能

## [v2.1] - 2021-12-16
* 1.ArduinoAPI更新
* 2.将LVGL部分绘图函数放到RAM执行，提升运行效率，不删除.sct文件
* 3.Adafruit_ST778驱动更新，适配新的SPI库
* 4.更新lvgl v8.1.1 dev
* 5.lv_conf.h更新，使用新的缩进
* 6.lv_monkey合入LVGL主线
* 7.去除LiveMap进入时的透明度渐变动画，提升流畅度
* 8.更新HAL_Power，充电检测上下拉可选
* 9.优化IMU和MAG初始化

## [v2.2] - 2021-12-30
* 1.添加系统软件架构说明
* 2.去除弃用的_LIS3MDL
* 3.修复使用strncpy()遗漏的'\0'结束符
* 4.添加AT32F435移植
* 5.LV_DISP_DEF_REFR_PERIOD 20ms -> 16ms
* 6.LV_MEM_SIZE 78KB -> 70KB
* 7.默认开启PNG解码器，受限于内存MCU无法使用
* 8.添加轨迹记录状态指示渐变动画
* 9.添加文本动画组件lv_anim_label，替换旧的lv_label_anim_effect
* 10.去除lv_settings

## [v2.3] - 2022-1-30
* 1.Arduino API 更新
* 2.添加wdg看门狗，系统卡死时自动重启
* 3.lvgl主程序更新
* 4.添加低内存开销(<50KB)的PNGdec解码器（暂不启用）
* 5.更新LiveMap，适配新的PNGdec
* 6.更新StatusBar，调整字体，新的轨迹记录状态指示渐变动画
* 7.ResourceManager从PageManager分离
* 8.lv_anim_label组件从lv_ext分离
* 9.添加lv_img_png组件

## [v2.4] - 2022-2-27
* 1.添加指定的Pack
* 2.AT32F435 Pack更新 2.0.0 -> 2.0.6
* 3.__wfi() -> __WFI()
* 4.移除lv_demo_conf.h
* 5.更新lvgl v8.3.0 dev
* 6.AT32F403A Stack size 0x2000 -> 0x1000

## [v2.5] - 2022-3-18
* 1.更新Adafruit_ST7789，支持颜色大小端切换
* 2.更新CommonMacro库
* 3.更新lv_conf.h
* 4.去除lv_lib_png，使用lvgl内置PNG库
* 5.DataProc 添加 DATA_PROC_INIT_STRUCT() 结构体初始化
* 6.StatusBar 统一走 DataCenter 通信，只保留初始化API
* 7.规范 DataProc 的 onEvent 回调函数的返回值
* 8.去除 Page.h 公共空间的 ARRAY_SIZE() 宏定义
* 9.ResourcePool::Font 默认返回 LV_FONT_DEFAULT，关闭不必要的内置字体
* 10.更新PageManager，lv_event_get_target() -> lv_event_get_current_target()

## [v2.6] - 2022-4-10
* 1.ArduinoAPI更新
* 2.整理 Core，统一移动到 MDK-ARM_F4XX/Platform 中
* 3.更新lvgl主程序
* 4.LV_SPRINTF_CUSTOM使能，减少FLASH占用
* 5.account->Pull()操作全部添加返回值检查
* 6.PageManager更新
* 7.页面Template添加生命周期LOG
* 8.DataCenter添加ACCOUNT_DISCARD_READ_DATA
* 9.__WFI() -> __wfi()
* 10.main.cpp复用
* 11.修复[TscanCode](https://github.com/Tencent/TscanCode)静态扫描出来的漏洞
* 12.添加Linux移植

## [v2.7] - 2022-6-3
* 1.Adafruit_ST7789: 添加多分辨率支持; 去除drawRGBBitmap(); 删除Adafruit_ST7789V2
* 2.AT32F403A: 更新Platform; 更新链接脚本，将lv_tlsf和font_bahnschrift_13载入RAM提升访问性能
* 3.AT32F435: 更新Platform
* 4.lv_conf.h: 同步主线配置; 使能LV_COLOR_SCREEN_TRANSP; WIN平台 GetTickCount() -> timeGetTime()
* 5.lvgl: 同步 commit 941d95b0491a1e78fadeeb5ea8aa552f82669336
* 6.App.cpp: 自动创建未设置的默认group; 设置scr的透明度和颜色; 添加rootStyle
* 7.PageManager: 添加PageBase.cpp; 规范成员变量命名; 添加Replace()方法; 支持设置RootDefaultStyle; 修复PM_Drag不生效
* 8.Pages/_Tempalte: 添加LOG输出
* 9.Pages/Dialplate: 同步PageManager更新
* 10.Pages/LiveMap: 同步PageManager更新
* 11.Pages/Startup: 同步PageManager更新; 使用Replace()方法替换Push()方法，支持BackHome()
* 12.Pages/SystemInfos: 同步PageManager更新; 优化item自动添加AttachEvent()
* 13.ResourcePool: 移除无用的gps_pin图片
* 14.lv_anim_label: lv_anim_label_set_text() -> lv_anim_label_push_text()
* 15.lv_img_png: 添加多色深支持
* 16.USER: 添加benchmark.inc，方便测试lvgl以及对比性能

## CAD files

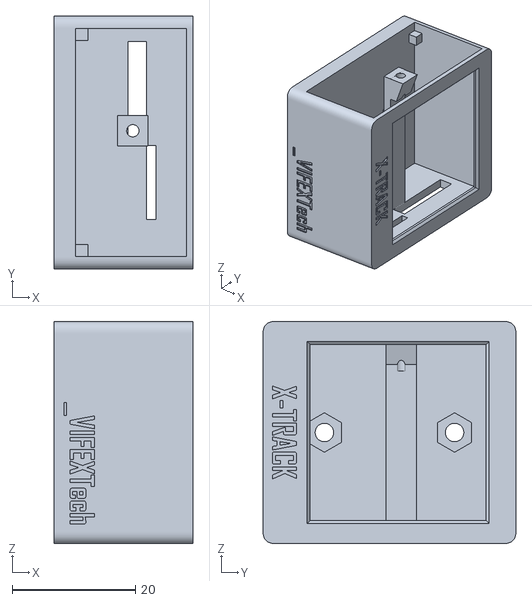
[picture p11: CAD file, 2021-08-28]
3D Model/外壳-主体.STL
22.5 x 41.0 x 36.0

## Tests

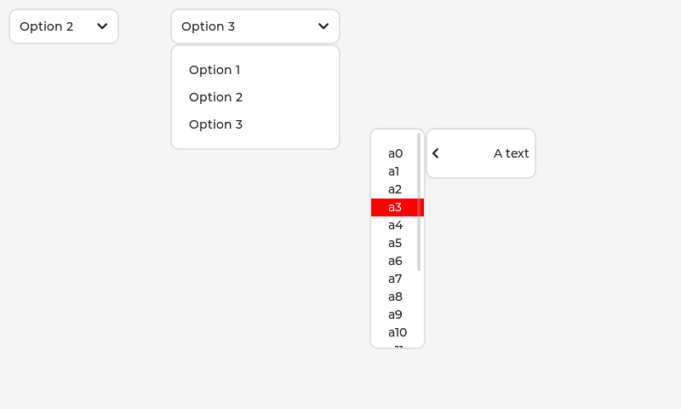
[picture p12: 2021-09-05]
Software/X-Track/Simulator/LVGL.Simulator/lvgl/tests/ref_imgs/dropdown_1.png

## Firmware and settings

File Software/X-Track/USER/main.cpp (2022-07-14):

/*
 * MIT License
 * Copyright (c) 2021 _VIFEXTech
 *
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
 * THE SOFTWARE IS PROVIDED "AS IS", WITHOUT WARRANTY OF ANY KIND, EXPRESS OR
 * IMPLIED, INCLUDING BUT NOT LIMITED TO THE WARRANTIES OF MERCHANTABILITY,
 * FITNESS FOR A PARTICULAR PURPOSE AND NONINFRINGEMENT. IN NO EVENT SHALL THE
 * AUTHORS OR COPYRIGHT HOLDERS BE LIABLE FOR ANY CLAIM, DAMAGES OR OTHER
 * LIABILITY, WHETHER IN AN ACTION OF CONTRACT, TORT OR OTHERWISE, ARISING FROM,
 * OUT OF OR IN CONNECTION WITH THE SOFTWARE OR THE USE OR OTHER DEALINGS IN THE
 * SOFTWARE.
 */
#include "Arduino.h"
#include "App/App.h"
#include "HAL/HAL.h"
#include "lvgl/lvgl.h"
#include "lv_port/lv_port.h"

#if LV_USE_DEMO_BENCHMARK

#include "benchmark.inc"

#else

static void setup()
{
    HAL::HAL_Init();
    lv_init();
    lv_port_init();

    App_Init();

    HAL::Power_SetEventCallback(App_Uninit);
    HAL::Memory_DumpInfo();
}

static void loop()
{
    HAL::HAL_Update();
    lv_task_handler();
    __wfi();
}

#endif

/**
  * @brief  Main Function
  * @param  None
  * @retval None
  */
int main(void)
{
    Core_Init();
    setup();
    for(;;)loop();
}

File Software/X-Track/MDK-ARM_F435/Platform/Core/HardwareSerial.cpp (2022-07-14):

/*
 * MIT License
 * Copyright (c) 2017 - 2022 _VIFEXTech
 *
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
 * THE SOFTWARE IS PROVIDED "AS IS", WITHOUT WARRANTY OF ANY KIND, EXPRESS OR
 * IMPLIED, INCLUDING BUT NOT LIMITED TO THE WARRANTIES OF MERCHANTABILITY,
 * FITNESS FOR A PARTICULAR PURPOSE AND NONINFRINGEMENT. IN NO EVENT SHALL THE
 * AUTHORS OR COPYRIGHT HOLDERS BE LIABLE FOR ANY CLAIM, DAMAGES OR OTHER
 * LIABILITY, WHETHER IN AN ACTION OF CONTRACT, TORT OR OTHERWISE, ARISING FROM,
 * OUT OF OR IN CONNECTION WITH THE SOFTWARE OR THE USE OR OTHER DEALINGS IN THE
 * SOFTWARE.
 */
#include "HardwareSerial.h"

typedef struct
{
    usart_data_bit_num_type data_bit;
    usart_parity_selection_type parity_selection;
    usart_stop_bit_num_type stop_bit;
} SERIAL_ConfigGrp_t;

static const SERIAL_ConfigGrp_t SERIAL_ConfigGrp[] =
{
    {USART_DATA_7BITS, USART_PARITY_NONE, USART_STOP_1_BIT},   // SERIAL_7N1
    {USART_DATA_7BITS, USART_PARITY_NONE, USART_STOP_2_BIT},   // SERIAL_7N2
    {USART_DATA_7BITS, USART_PARITY_EVEN, USART_STOP_1_BIT},   // SERIAL_7E1
    {USART_DATA_7BITS, USART_PARITY_EVEN, USART_STOP_2_BIT},   // SERIAL_7E2
    {USART_DATA_7BITS, USART_PARITY_ODD,  USART_STOP_1_BIT},   // SERIAL_7O1
    {USART_DATA_7BITS, USART_PARITY_ODD,  USART_STOP_2_BIT},   // SERIAL_7O2
    {USART_DATA_7BITS, USART_PARITY_NONE, USART_STOP_0_5_BIT}, // SERIAL_7N0_5
    {USART_DATA_7BITS, USART_PARITY_NONE, USART_STOP_1_5_BIT}, // SERIAL_7N1_5
    {USART_DATA_7BITS, USART_PARITY_EVEN, USART_STOP_0_5_BIT}, // SERIAL_7E0_5
    {USART_DATA_7BITS, USART_PARITY_EVEN, USART_STOP_1_5_BIT}, // SERIAL_7E1_5
    {USART_DATA_7BITS, USART_PARITY_ODD,  USART_STOP_0_5_BIT}, // SERIAL_7O0_5
    {USART_DATA_7BITS, USART_PARITY_ODD,  USART_STOP_1_5_BIT}, // SERIAL_7O1_5

    {USART_DATA_8BITS, USART_PARITY_NONE, USART_STOP_1_BIT},   // SERIAL_8N1
    {USART_DATA_8BITS, USART_PARITY_NONE, USART_STOP_2_BIT},   // SERIAL_8N2
    {USART_DATA_8BITS, USART_PARITY_EVEN, USART_STOP_1_BIT},   // SERIAL_8E1
    {USART_DATA_8BITS, USART_PARITY_EVEN, USART_STOP_2_BIT},   // SERIAL_8E2
    {USART_DATA_8BITS, USART_PARITY_ODD,  USART_STOP_1_BIT},   // SERIAL_8O1
    {USART_DATA_8BITS, USART_PARITY_ODD,  USART_STOP_2_BIT},   // SERIAL_8O2
    {USART_DATA_8BITS, USART_PARITY_NONE, USART_STOP_0_5_BIT}, // SERIAL_8N0_5
    {USART_DATA_8BITS, USART_PARITY_NONE, USART_STOP_1_5_BIT}, // SERIAL_8N1_5
    {USART_DATA_8BITS, USART_PARITY_EVEN, USART_STOP_0_5_BIT}, // SERIAL_8E0_5
    {USART_DATA_8BITS, USART_PARITY_EVEN, USART_STOP_1_5_BIT}, // SERIAL_8E1_5
    {USART_DATA_8BITS, USART_PARITY_ODD,  USART_STOP_0_5_BIT}, // SERIAL_8O0_5
    {USART_DATA_8BITS, USART_PARITY_ODD,  USART_STOP_1_5_BIT}, // SERIAL_8O1_5

    {USART_DATA_9BITS, USART_PARITY_NONE, USART_STOP_1_BIT},   // SERIAL_9N1
    {USART_DATA_9BITS, USART_PARITY_NONE, USART_STOP_2_BIT},   // SERIAL_9N2
    {USART_DATA_9BITS, USART_PARITY_EVEN, USART_STOP_1_BIT},   // SERIAL_9E1
    {USART_DATA_9BITS, USART_PARITY_EVEN, USART_STOP_2_BIT},   // SERIAL_9E2
    {USART_DATA_9BITS, USART_PARITY_ODD,  USART_STOP_1_BIT},   // SERIAL_9O1
    {USART_DATA_9BITS, USART_PARITY_ODD,  USART_STOP_2_BIT},   // SERIAL_9O2
    {USART_DATA_9BITS, USART_PARITY_NONE, USART_STOP_0_5_BIT}, // SERIAL_9N0_5
    {USART_DATA_9BITS, USART_PARITY_NONE, USART_STOP_1_5_BIT}, // SERIAL_9N1_5
    {USART_DATA_9BITS, USART_PARITY_EVEN, USART_STOP_0_5_BIT}, // SERIAL_9E0_5
    {USART_DATA_9BITS, USART_PARITY_EVEN, USART_STOP_1_5_BIT}, // SERIAL_9E1_5
    {USART_DATA_9BITS, USART_PARITY_ODD,  USART_STOP_0_5_BIT}, // SERIAL_9O0_5
    {USART_DATA_9BITS, USART_PARITY_ODD,  USART_STOP_1_5_BIT}, // SERIAL_9O1_5
};

/**
  * @brief  串口对象构造函数
  * @param  串口外设地址
  * @retval 无
  */
HardwareSerial::HardwareSerial(usart_type* usart)
    : _USARTx(usart)
    , _callbackFunction(NULL)
    , _rxBufferHead(0)
    , _rxBufferTail(0)
{
    memset(_rxBuffer, 0, sizeof(_rxBuffer));
}

/**
  * @brief  串口中断入口
  * @param  无
  * @retval 无
  */
void HardwareSerial::IRQHandler()
{
    if(usart_flag_get(_USARTx, USART_RDBF_FLAG) != RESET)
    {
        uint8_t c = usart_data_receive(_USARTx);
        uint16_t i = (uint16_t)(_rxBufferHead + 1) % SERIAL_RX_BUFFER_SIZE;
        if (i != _rxBufferTail)
        {
            _rxBuffer[_rxBufferHead] = c;
            _rxBufferHead = i;
        }

        if(_callbackFunction)
        {
            _callbackFunction(this);
        }
        usart_flag_clear(_USARTx, USART_RDBF_FLAG);
    }
}

/**
  * @brief  串口初始化
  * @param  BaudRate: 波特率
  * @param  Config: 配置参数
  * @param  PreemptionPriority: 抢占优先级
  * @param  SubPriority: 从优先级
  * @retval 无
  */
void HardwareSerial::begin(
    uint32_t baudRate,
    SERIAL_Config_t config,
    uint8_t preemptionPriority,
    uint8_t subPriority
)
{
    gpio_type *GPIOx;
    gpio_init_type gpio_init_struct;
    uint16_t Tx_Pin, Rx_Pin;
    IRQn_Type USARTx_IRQn;

    if(_USARTx == USART1)
    {
        GPIOx = GPIOA;
        Tx_Pin = GPIO_Pin_9;
        Rx_Pin = GPIO_Pin_10;
        USARTx_IRQn = USART1_IRQn;

        crm_periph_clock_enable(CRM_GPIOA_PERIPH_CLOCK, TRUE);
        crm_periph_clock_enable(CRM_USART1_PERIPH_CLOCK, TRUE);
    }
    else if(_USARTx == USART2)
    {
        GPIOx = GPIOA;
        Tx_Pin = GPIO_Pin_2;
        Rx_Pin = GPIO_Pin_3;
        USARTx_IRQn = USART2_IRQn;

        crm_periph_clock_enable(CRM_GPIOA_PERIPH_CLOCK, TRUE);
        crm_periph_clock_enable(CRM_USART2_PERIPH_CLOCK, TRUE);
    }
    else if(_USARTx == USART3)
    {
        GPIOx = GPIOB;
        Tx_Pin = GPIO_Pin_10;
        Rx_Pin = GPIO_Pin_11;
        USARTx_IRQn = USART3_IRQn;

        crm_periph_clock_enable(CRM_GPIOB_PERIPH_CLOCK, TRUE);
        crm_periph_clock_enable(CRM_USART3_PERIPH_CLOCK, TRUE);
    }
    else
    {
        return;
    }

    gpio_default_para_init(&gpio_init_struct);
    gpio_init_struct.gpio_pins =  Tx_Pin | Rx_Pin;
    gpio_init_struct.gpio_drive_strength = GPIO_DRIVE_STRENGTH_STRONGER;
    gpio_init_struct.gpio_mode = GPIO_MODE_MUX;
    gpio_init_struct.gpio_pull = GPIO_PULL_NONE;
    gpio_init_struct.gpio_out_type  = GPIO_OUTPUT_PUSH_PULL;
    gpio_init(GPIOx, &gpio_init_struct);

    gpio_pin_mux_config(GPIOx, GPIO_GetPinSource(Tx_Pin), GPIO_MUX_7);
    gpio_pin_mux_config(GPIOx, GPIO_GetPinSource(Rx_Pin), GPIO_MUX_7);

    usart_init(_USARTx, baudRate, SERIAL_ConfigGrp[config].data_bit, SERIAL_ConfigGrp[config].stop_bit);
    usart_parity_selection_config(_USARTx, SERIAL_ConfigGrp[config].parity_selection);
    usart_transmitter_enable(_USARTx, TRUE);
    usart_receiver_enable(_USARTx, TRUE);

    nvic_irq_enable(USARTx_IRQn, preemptionPriority, subPriority);
    usart_interrupt_enable(_USARTx, USART_RDBF_INT, TRUE);

    usart_enable(_USARTx, TRUE);
}

/**
  * @brief  关闭串口
  * @param  无
  * @retval 无
  */
void HardwareSerial::end(void)
{
    usart_interrupt_enable(_USARTx, USART_RDBF_INT, FALSE);
    usart_enable(_USARTx, FALSE);
}
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

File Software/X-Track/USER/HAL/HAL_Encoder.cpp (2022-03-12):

#include "HAL.h"
#include "ButtonEvent/ButtonEvent.h"

static ButtonEvent EncoderPush(CONFIG_POWER_SHUTDOWM_DELAY);

static bool EncoderEnable = true;
static volatile int32_t EncoderDiff = 0;
static bool EncoderDiffDisable = false;

static void Buzz_Handler(int dir)
{
    static const uint16_t freqStart = 2000;
    static uint16_t freq = freqStart;
    static uint32_t lastRotateTime;

    if(millis() - lastRotateTime > 1000)
    {
        freq = freqStart;
    }
    else
    {
        if(dir > 0)
        {
            freq += 100;
        }

        if(dir < 0)
        {
            freq -= 100;
        }

        freq = constrain(freq, 100, 20 * 1000);
    }

    lastRotateTime = millis();
    HAL::Buzz_Tone(freq, 5);
}

static void Encoder_EventHandler()
{
    if(!EncoderEnable || EncoderDiffDisable)
    {
        return;
    }

    int dir = (digitalRead(CONFIG_ENCODER_B_PIN) == LOW ? -1 : +1);
    EncoderDiff += dir;
    Buzz_Handler(dir);
}

static void Encoder_PushHandler(ButtonEvent* btn, int event)
{
    if(event == ButtonEvent::EVENT_PRESSED)
    {
        EncoderDiffDisable = true;
    }
    else if(event == ButtonEvent::EVENT_RELEASED)
    {
        EncoderDiffDisable = false;
    }
    else if(event == ButtonEvent::EVENT_LONG_PRESSED)
    {
        HAL::Power_Shutdown();
        HAL::Audio_PlayMusic("Shutdown");
    }
}

void HAL::Encoder_Init()
{
    pinMode(CONFIG_ENCODER_A_PIN, INPUT_PULLUP);
    pinMode(CONFIG_ENCODER_B_PIN, INPUT_PULLUP);
    pinMode(CONFIG_ENCODER_PUSH_PIN, INPUT_PULLUP);

    attachInterrupt(CONFIG_ENCODER_A_PIN, Encoder_EventHandler, FALLING);

    EncoderPush.EventAttach(Encoder_PushHandler);
}

void HAL::Encoder_Update()
{
    EncoderPush.EventMonitor(Encoder_GetIsPush());
}

int32_t HAL::Encoder_GetDiff()
{
    int32_t diff = EncoderDiff;
    EncoderDiff = 0;
    return diff;
}

bool HAL::Encoder_GetIsPush()
{
    if(!EncoderEnable)
    {
        return false;
    }
    
    return (digitalRead(CONFIG_ENCODER_PUSH_PIN) == LOW);
}

void HAL::Encoder_SetEnable(bool en)
{
    EncoderEnable = en;
}
